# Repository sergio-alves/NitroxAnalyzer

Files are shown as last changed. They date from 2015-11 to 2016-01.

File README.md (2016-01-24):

# NitroxAnalyzer
This repository contains everything needed to build a nitrox analyzer that uses a compatible R17 O2 cell and that connects to a mobile phone running on Android.

The finished product:

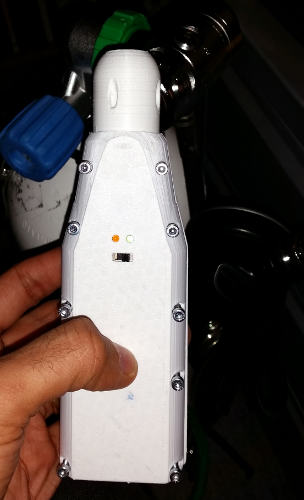
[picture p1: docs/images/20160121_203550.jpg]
The nitrox analyser V2


Read [the wiki page](https://github.com/sergio-alves/NitroxAnalyzer/wiki) to get more information about the project.

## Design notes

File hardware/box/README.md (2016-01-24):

## 3D printed box proprosition

To enclose the electronic circuitry, battery and o2 cell I propose the following box design.

* box-bottom.stl
* box-top.stl
* o2-cell-support.stl

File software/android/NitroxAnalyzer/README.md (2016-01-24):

# Nitrox Analyzer for Android

Because i'm a scubadiver, I decided to create a simple
device to read the O2 concentration of gas blends that I
breath.

I created a first version of the device using a screen
and two buttons. It worked, but someone suggested me another idea :

Why not replace the screen and buttons by an Android
application?

Benefits : Better and easy UI, less electronics, and allows me
to show that I can create an Android application that gets
data from an electronic device through a bluetooth connection.

And.... tada!!!

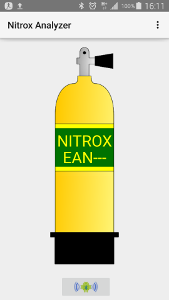
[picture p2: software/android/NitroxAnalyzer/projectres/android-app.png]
The application interface


## How it works

If automatic mode (see Settings), at startup a connection is
setup between application and the device. You can select the
interface to use in the Settings interface. If not in automatic
mode just push the radio-android :) button to start connection.

If you receive a message to ask you to activate the bluetooth
interface, just accept and click again on the connection button.
If connection succeed the animation stops.

After successful connection, comes the calibration phase.
The application will get the data coming from the device and
will average it. Calibration stops when the delta between
current value and measured average till now reaches < 1% O2.

After calibration you can start measuring all the gas blends
you want. If the interface is in continuous o2 reading (see
settings) then you just need to approach the device to the
fittings of your tank slowly open it and see the value. You
can stop when the value remains constant. If not in automatic
do the same but don't forget to click on ReadO2 button. The
analyse will finish when delta reaches < 1% O2 .

## License
GPL License

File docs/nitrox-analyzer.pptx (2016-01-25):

## DIY Nitrox Analyzer

By Sergio Alves

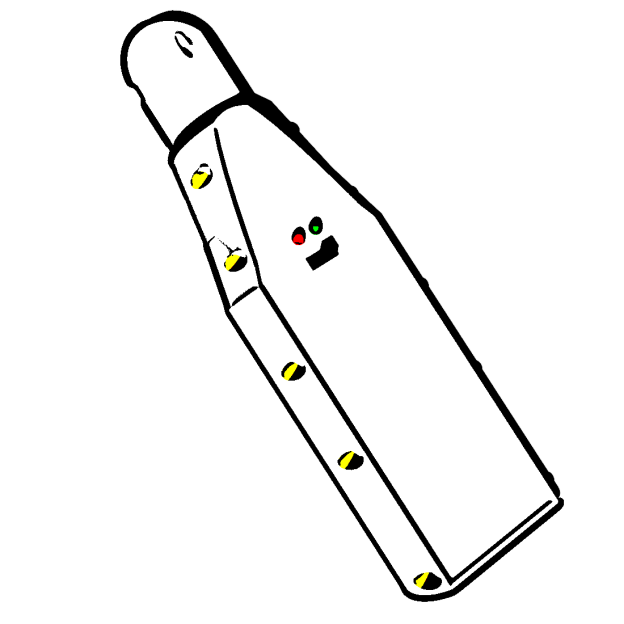
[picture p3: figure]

## Inception

- As a TEC scuba diver I often breath hyperoxic gases while decompressing (it accelerates decompression).
- To avoid entering into convulsions… and die… because of a too high ppO2, it’s important to know the precise O2 % of the gas mix and then calc the MOD (maximum operating depth) => never breath it below MOD
- Commercial analyzers are simple boxes with an O2 cell and a kind of Multimeter (really simple devices) but very expensive > 200$

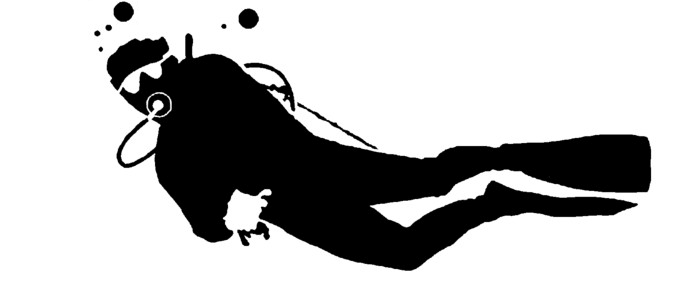
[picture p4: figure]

## Project Goals

- Build a reliable DIY device
  - Precision per bit ~300 nV
  - Price < 100 CHF
  - Open source
- Demonstrate the capacity to
  - lead a project from an idea to a finite product
  - develop C++ firmware
  - develop UI for android
  - use a Bluetooth connection
  - model/design and print a complex container (box)

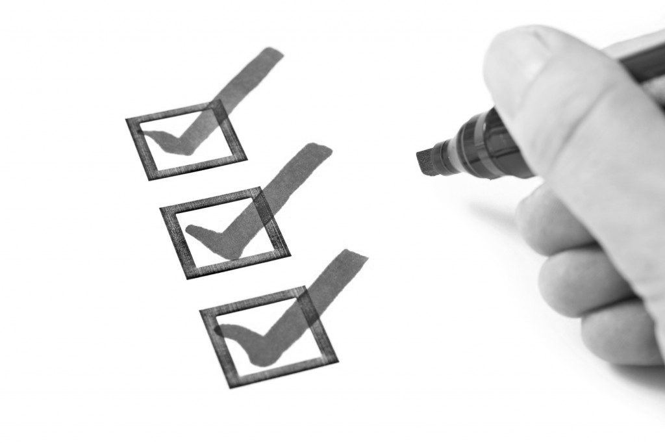
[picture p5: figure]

## How should it work ?

- Switch Analyzer on
- Launch Android application
  - If not in auto connect mode click the connection button
- After successful connection the device will enter in auto calibration mode (to get the O2 cell value for the current gaz (air ~ 20.9 % O2)
- After calibration the controller will read continuously the sensor at a rate of 1S/s (sample/second) and the application will display the O2 value

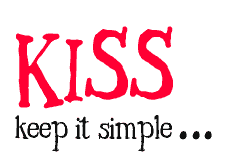
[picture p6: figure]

## How to integrate?

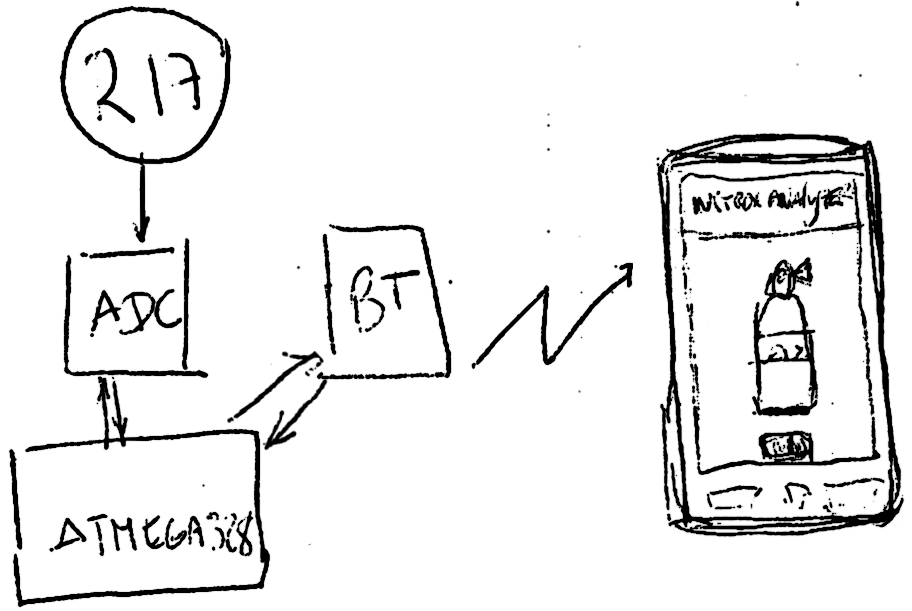
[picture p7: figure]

## Components

- Hardware
  - A 3D printed box
  - An Arduino Nano for device control
  - A Bluetooth serial module
  - A 24 bits ADC for a high signal measurement accuracy
  - R17 Medical O2 Oxygen cell sensor
- Software
  - C++ Firmware embedded in Atmega328
    - 16MHz controller with 2 Kb Ram, 32 Kb Rom (limited resources)
  - Java mobile application running on Android OS

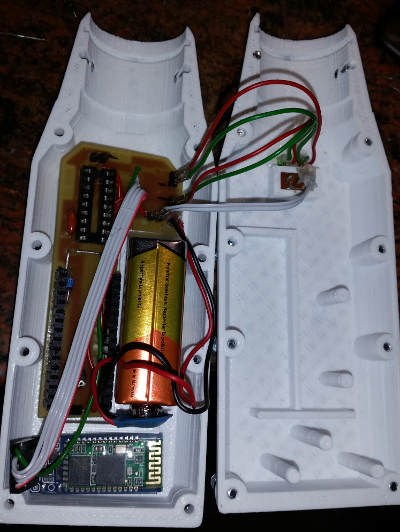
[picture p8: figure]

## Challenges

- Software
  - Create an easily upgradable protocol handler in both firmware and mobile application and make them communicate
  - Create a driver to “drive” the ADS1210 chip
- Hardware
  - Develop the smallest box able to hold a R17 cell, a Nano board, a 9V battery and a Bluetooth module
- Create something precise enough to be confident using it and that runs straight forward
- Develop a device without any kind of physical user interaction (buttons, screen, audio)

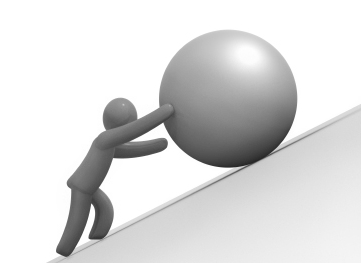
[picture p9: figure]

## How to improve?

- Features
  - connection to a Bluetooth analyzer
  - auto calibration
  - continuous o2 measurement
  - displaying o2 cell dates (install, validity)

- Wanted features
  - update install validity dates
  - display progress bar to help to know when a measure is valid
  - keep a track of read values
  - creates a more TEC view with higher precision
  - allow to have 2 O2 cells to have a duplicate measure. This will render the device very safe and avoid wrong measures

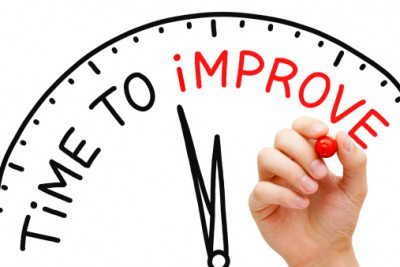
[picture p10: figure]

## Some time later…

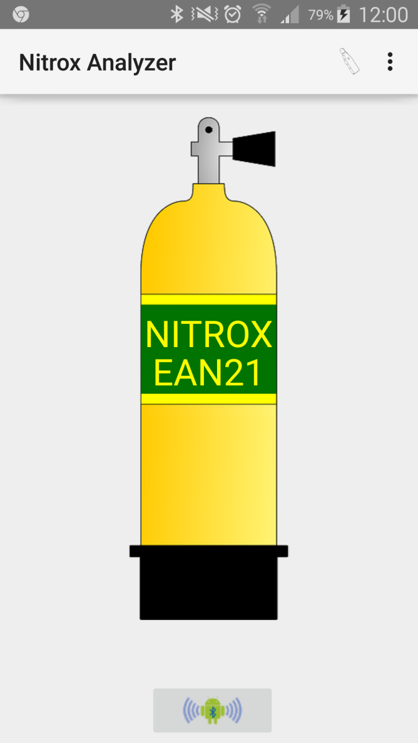
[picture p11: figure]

## Because I belive in pen Source

- All files, schemas, images, source codes are available and licensed under GNU GPL3 on
https://github.com/sergio-alves/NitroxAnalyzer

## Live demo

- Lets see how KISS is it !!!

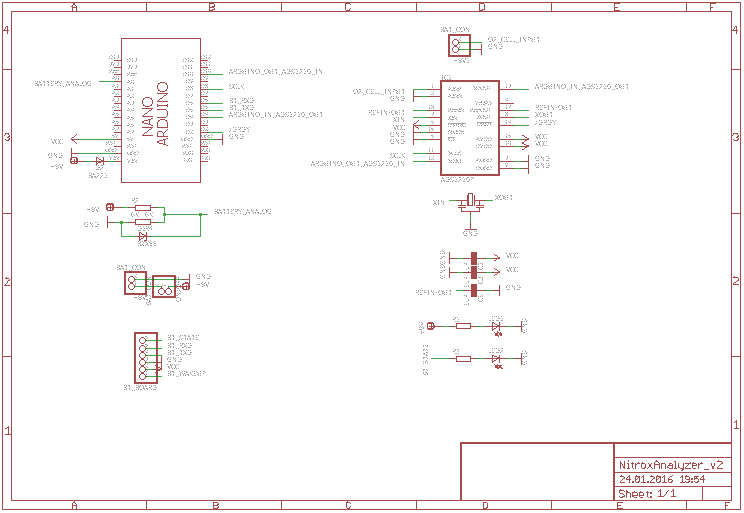
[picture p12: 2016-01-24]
docs/images/schematic.png

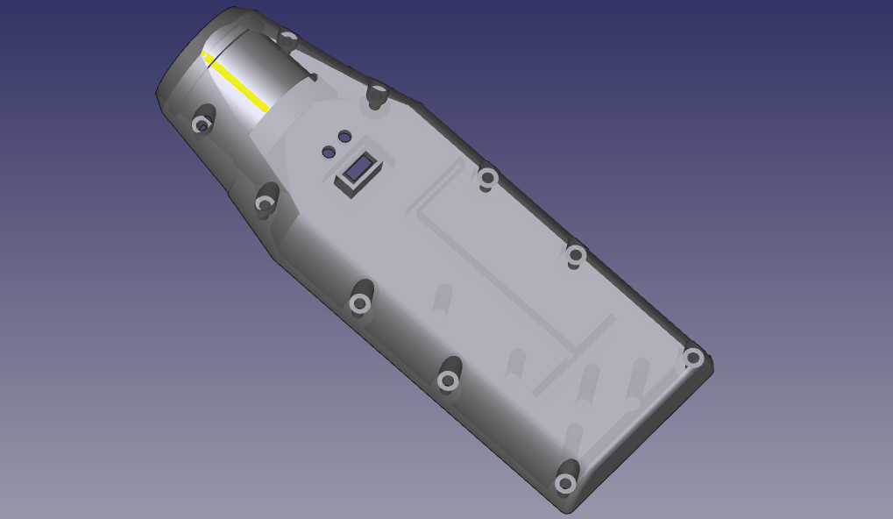
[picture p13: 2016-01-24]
docs/images/box-top.png

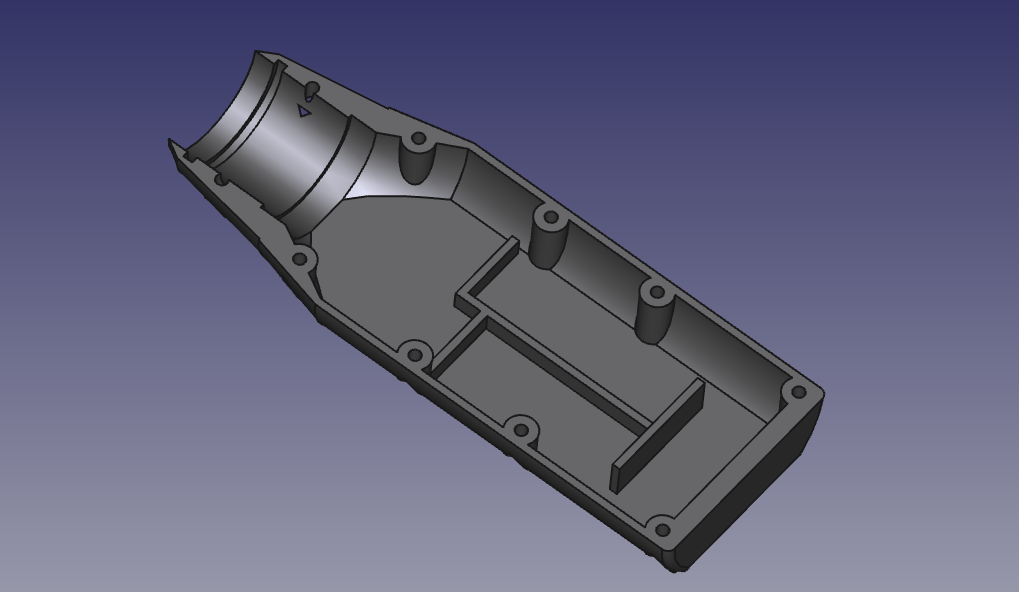
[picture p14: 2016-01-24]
docs/images/box-bottom.png

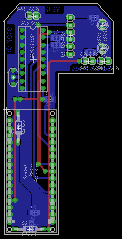
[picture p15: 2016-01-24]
docs/images/board.png

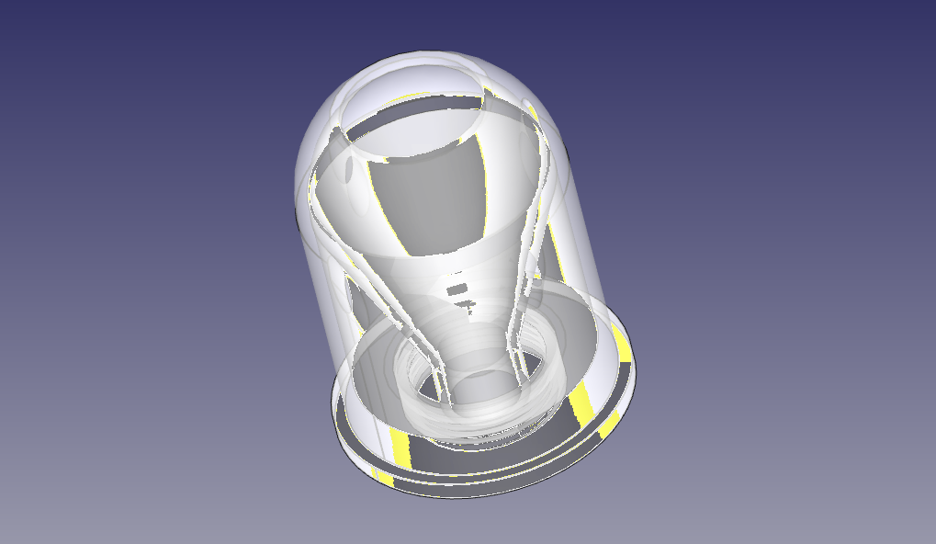
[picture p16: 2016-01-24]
docs/images/o2-cell-support.png

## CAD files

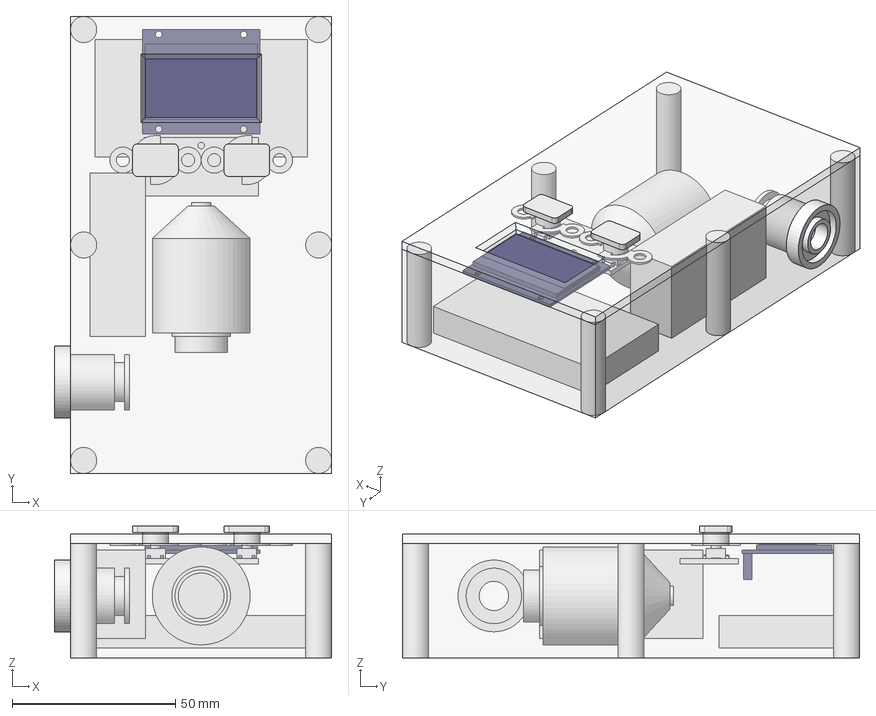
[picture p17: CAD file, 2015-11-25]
box/freecad files/NitroxAnalyzer.FCStd
85.0 x 140.0 x 40.4 mm
battery
board_nano
oled-screen
case-top
start-button
buttons-pcb
calibrate-button
o2_cell
propeller
fittings-connector
flow-pipe
bottom-box

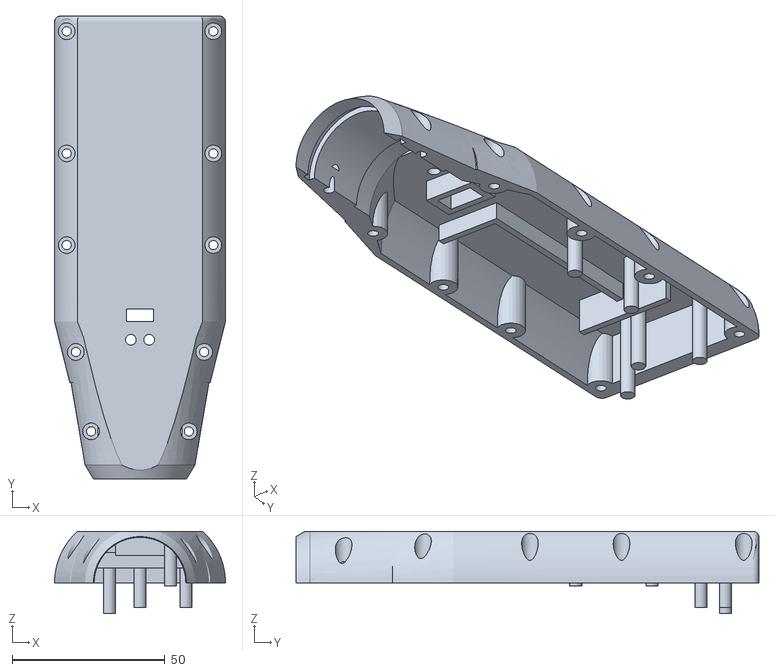
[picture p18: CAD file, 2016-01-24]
hardware/box/box-top.stl
56.0 x 151.6 x 27.0

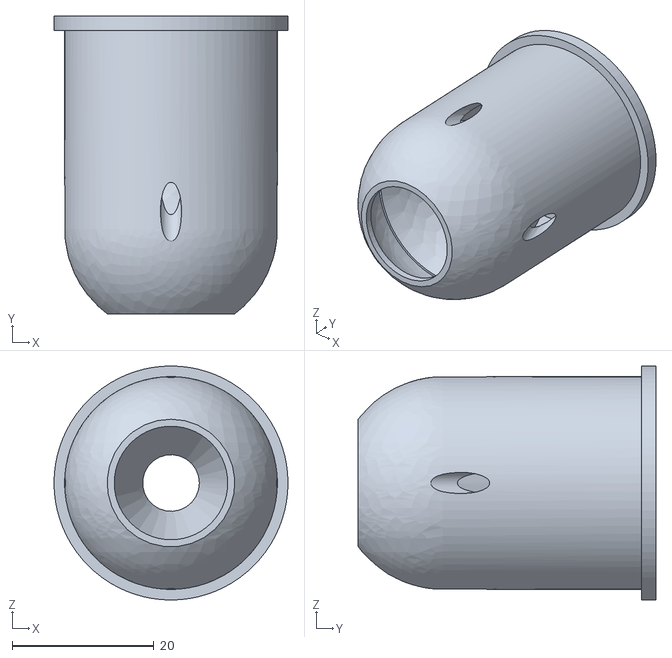
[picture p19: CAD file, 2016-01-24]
hardware/box/o2-cell-support.stl
33.0 x 42.0 x 33.0

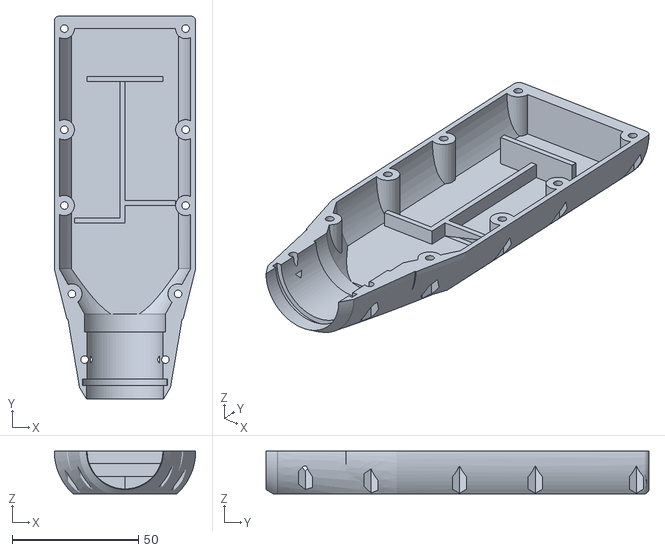
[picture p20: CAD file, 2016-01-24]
hardware/box/box-bottom.stl
56.0 x 151.6 x 17.0

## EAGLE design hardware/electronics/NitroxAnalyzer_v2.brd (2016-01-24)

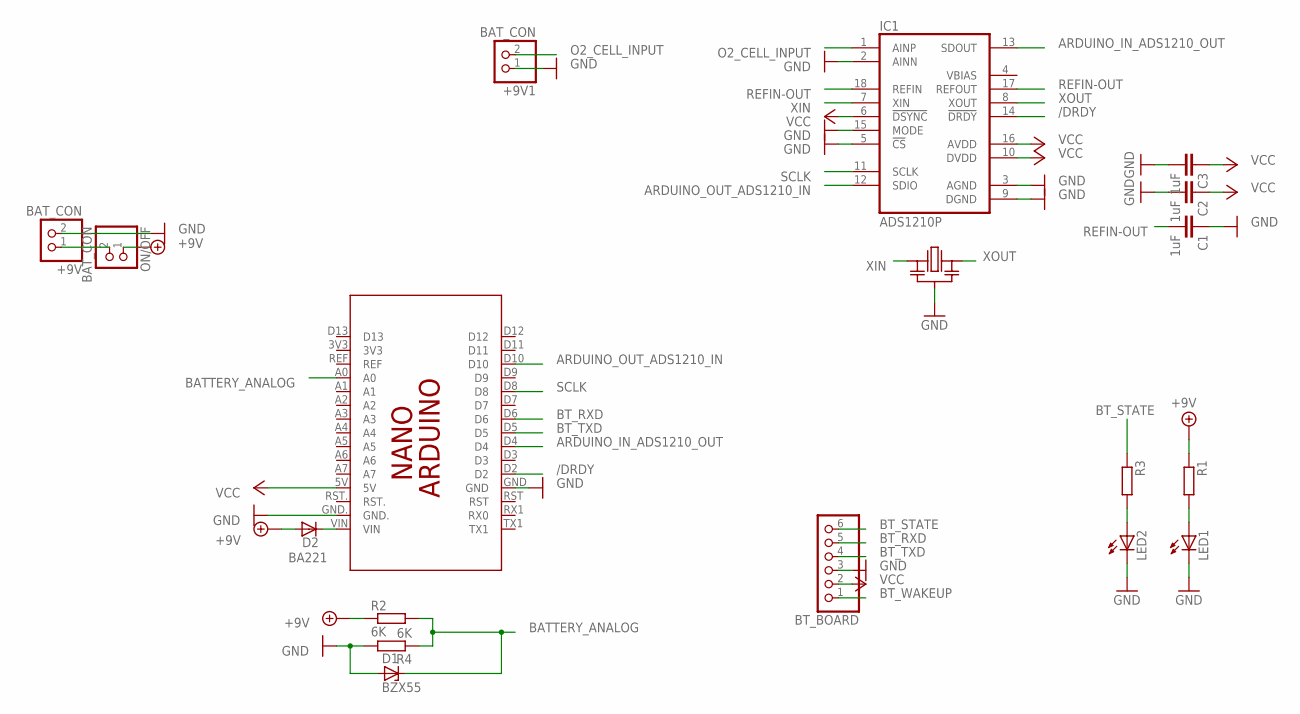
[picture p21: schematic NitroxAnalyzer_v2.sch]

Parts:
+9V, +9V1: BAT_CON; 1X02
BT_BOARD: PINHD-1X6; 1X06
C1, C2, C3: 1uF; C1206
D1: BZX55; DO35Z10
D2: BA221; DO35-10
IC1: ADS1210P; DIL18
LED1, LED2: LED3MM
ON/OFF: BAT_CON; 1X02
PCB1: ARDUINO_NANO_SOCKET
R1, R3: R-EU_R1206; R1206
R2, R4: 6K; R1206
U$2: RESONATOR

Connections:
+9V: D2.A, ON/OFF.1, R1.1, R2.1
/DRDY: IC1.14 (!DRDY), PCB1.D2
ARDUINO_IN_ADS1210_OUT: IC1.13 (SDOUT), PCB1.D4
ARDUINO_OUT_ADS1210_IN: IC1.12 (SDIO), PCB1.D10
BATTERY_ANALOG: D1.C, PCB1.A0, R2.2, R4.1
BT_RXD: BT_BOARD.5, PCB1.D6
BT_STATE: BT_BOARD.6, R3.1
BT_TXD: BT_BOARD.4, PCB1.D5
BT_WAKEUP: BT_BOARD.1
GND: +9V.2, +9V1.1, BT_BOARD.3, C1.1, C2.2, C3.2, D1.A, IC1.2 (AINN), IC1.3 (AGND), IC1.5 (!CS), IC1.9 (DGND), IC1.15 (MODE), LED1.K (C), LED2.K (C), PCB1.GND, PCB1.GND., R4.2, U$2.P$2 (GND)
unnamed: D2.C, PCB1.VIN
unnamed: LED1.A, R1.2
unnamed: LED2.A, R3.2
unnamed: +9V.1, ON/OFF.2
O2_CELL_INPUT: +9V1.2, IC1.1 (AINP)
REFIN-OUT: C1.2, IC1.17 (REFOUT), IC1.18 (REFIN)
SCLK: IC1.11 (SCLK), PCB1.D8
VCC: BT_BOARD.2, C2.1, C3.1, IC1.6 (!DSYNC), IC1.10 (DVDD), IC1.16 (AVDD), PCB1.5V
XIN: IC1.7 (XIN), U$2.P$1 (IN)
XOUT: IC1.8 (XOUT), U$2.P$3 (OUT)

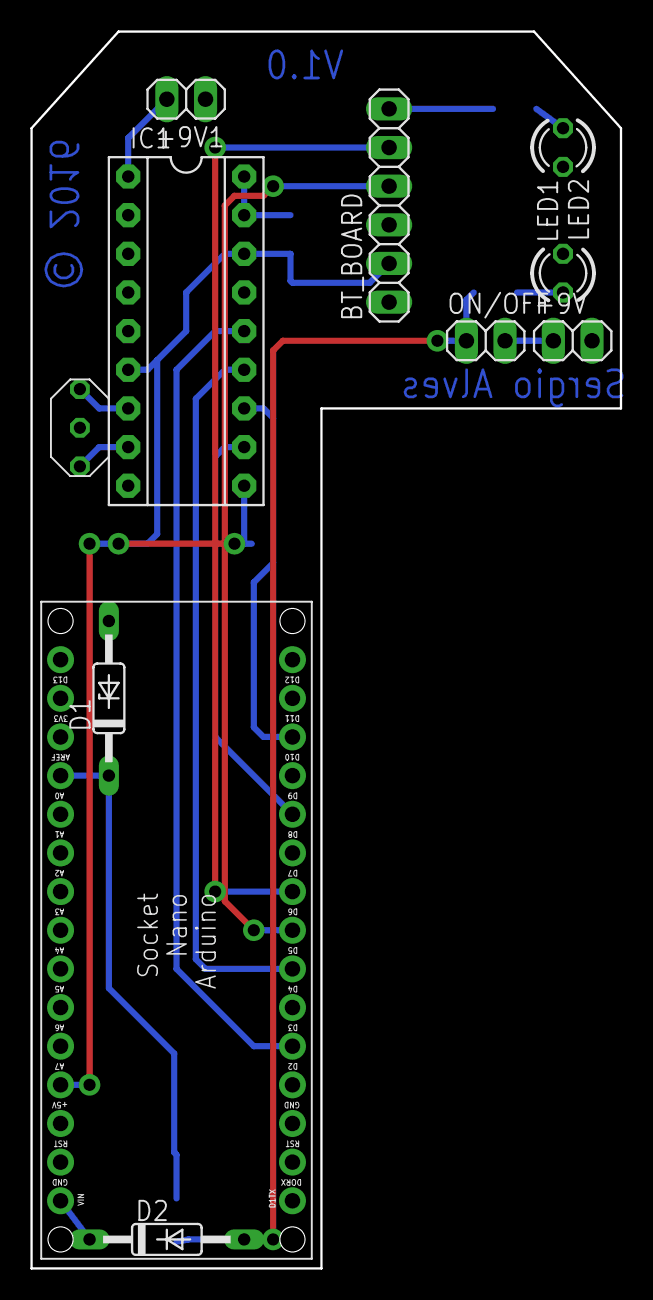
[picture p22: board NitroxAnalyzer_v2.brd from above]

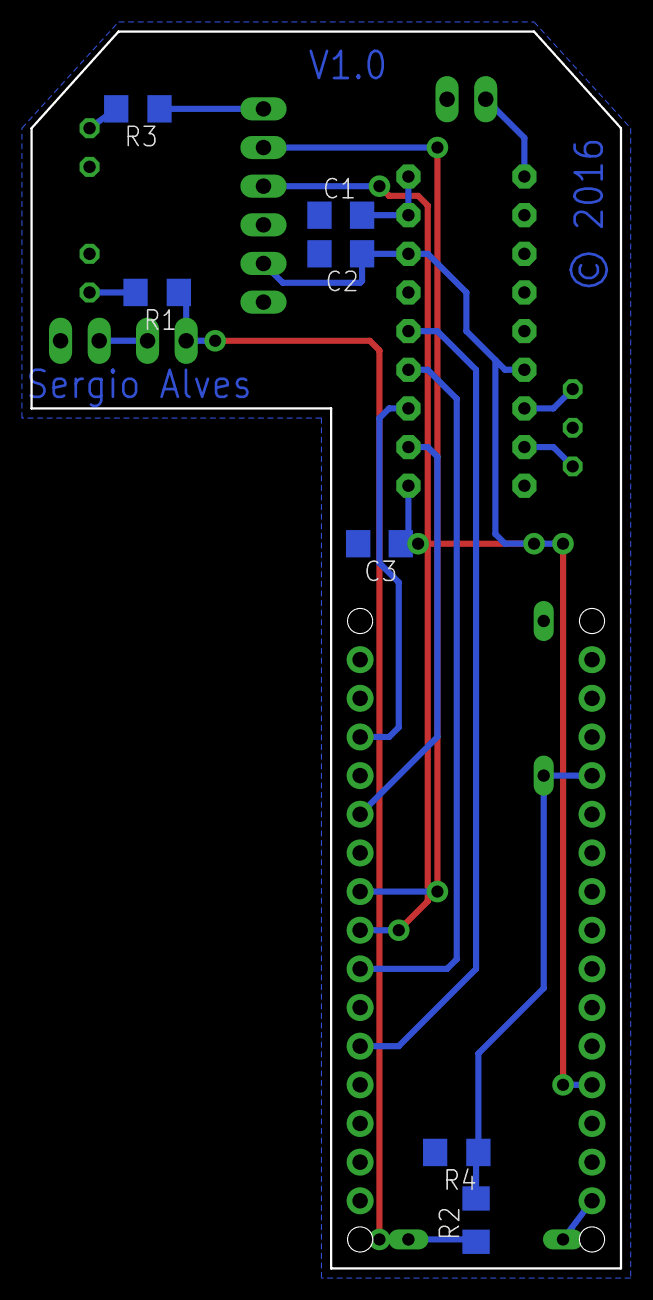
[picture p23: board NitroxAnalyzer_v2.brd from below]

Board: 2 copper layers, 38.7 x 81.3 mm, 18 parts (7 on the bottom side), 19 nets.

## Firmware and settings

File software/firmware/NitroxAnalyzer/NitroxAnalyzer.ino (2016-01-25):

#include <SoftwareSerial.h>
#include <SPI.h>
#include <stdio.h>
#include <EEPROM\EEPROM.h>
#include "ADS1210Driver.h"
#include "SerialProtocolHandler.h"

#define SOFTWARE_RX_PIN					5
#define SOFTWARE_TX_PIN					6

#define ADS1210_CLK						8
#define ARDUINO_OUT_ADS1210_IN			10
#define ARDUINO_IN_ADS1210_OUT			4

#define BATTERY_AD_INPUT				A0

#define EEPROM_STORED_DATA_SIZE			12
#define EEPROM_CONFIG_START_ADDRESS		0

typedef struct {
	int day;
	int month;
	int year;
} date;

typedef union {
	byte data[EEPROM_STORED_DATA_SIZE];
	struct {
		long clean;
		struct {
			date install_date; //6 bytes
			date change_date;  //6 bytes
		} O2Cell; // 12 bytes
	};
} EEPROMContent;

typedef union {
	struct {
		unsigned crap : 1;
		unsigned value : 12;
		unsigned padding : 3;
	} bitfield;
	struct {
		byte low;
		byte high;
	}bytes;
	unsigned int raw;
} DWORD_MAX_187_DATA_FORMAT; //2 bytes

typedef union {
	char bytes[6];
	struct {
		unsigned int start;
		unsigned int current;
		unsigned int end;
	}structuredData;
} SendingBuffer;

enum States {
	STATE_IDLE,
	STATE_EXECUTE_GET_AVERAGE_INIT,
	STATE_EXECUTE_GET_AVERAGE_READ_VALUES,
	STATE_EXECUTE_GET_AVERAGE_RETURN_RESPONSE,
	STATE_EXECUTE_GET_BATTERY_LOAD,
	STATE_EXECUTE_GET_O2_CELL_INSTALL_DATE,
	STATE_EXECUTE_SET_O2_CELL_INSTALL_DATE,
};

SoftwareSerial BTSerial = SoftwareSerial(SOFTWARE_RX_PIN, SOFTWARE_TX_PIN);
SerialProtocolHandler protocolHandler = SerialProtocolHandler(BTSerial);
EEPROMContent eeprom;

#define isEEPROMClean() eeprom.clean==0xCAFEBABE

SendingBuffer sb;
DWORD_MAX_187_DATA_FORMAT current;
char buffer[128];
char c;
SerialCommand * command;
States state = STATE_IDLE;
bool readMeasure = false;
unsigned long average;
int counter = 0;
int maxIterations = 10;
long min = 0x7FFFFFFF;
long max = 0x80000000;


/* This app setup*/
void setup()
{
	Serial.begin(115200);
	BTSerial.begin(9600);

	attachInterrupt(digitalPinToInterrupt(2), newMeasure, FALLING);

	ads1210.begin(ADS1210_CLK, ARDUINO_OUT_ADS1210_IN, ARDUINO_IN_ADS1210_OUT);

	pinMode(BATTERY_AD_INPUT, INPUT);

	//Load eeprom
	for (int i = 0; i < EEPROM_STORED_DATA_SIZE; i++) {
		eeprom.data[i] = EEPROM.read(EEPROM_CONFIG_START_ADDRESS + i);
	}
}

void newMeasure() {
	readMeasure = true;
}

void readAndIncrement() {
	long l;

	if (readMeasure) {
		l = ads1210.readDataOutputRegister();

		if (l < min)
			min = l;
		if (l > max)
			max = l;

		average += l;
		counter++;
	}
}

void loop() {
	unsigned int mappedVal = 0, val = 0;

	//Handle protocol
	switch (state) {
	case STATE_EXECUTE_GET_AVERAGE_INIT:
		maxIterations = ((GetAverageCommand *)command)->getIterations();
		state = STATE_EXECUTE_GET_AVERAGE_READ_VALUES;
		break;
	case STATE_EXECUTE_GET_AVERAGE_READ_VALUES:
		if (counter == maxIterations) { state = STATE_EXECUTE_GET_AVERAGE_RETURN_RESPONSE; }
		else { readAndIncrement(); }
		break;
	case STATE_EXECUTE_GET_AVERAGE_RETURN_RESPONSE:
		average = (long)(average / (float)maxIterations);
		((GetAverageCommand *)command)->setAverage(average);

		protocolHandler.sendResponse(command);

		sprintf(buffer, "Average ater %i iterations : (min, max, max-min, average)=>(%li, %li, %li, %li)\0", maxIterations, min, max, max - min, average);
		Serial.println(buffer);

		counter = 0;
		average = 0;
		min = 0x7FFFFFFF;
		max = 0x80000000;
		state = STATE_IDLE;
		break;
	case STATE_EXECUTE_GET_BATTERY_LOAD:
		//long v = analogRead(BATTERY_AD_INPUT);
		//When battery is full  A0 reads value 4.4 Volts => 0.55 * 8V
		//		int value = map(analogRead(BATTERY_AD_INPUT), 0, 1023, 0, 5);
		//9 = 4.5 = batter full
		//6 = 3 = battery quite empty

		// ==> 950 max  600 min
		val = analogRead(BATTERY_AD_INPUT);
		delayMicroseconds(100);
		val = analogRead(BATTERY_AD_INPUT);
		Serial.print("Analog read A0 = ");
		Serial.println(val);

		if (val < 650)
			mappedVal = 0;
		if (val > 850)
			mappedVal = 100;
		if (val >= 650 && val <= 850)
			mappedVal = (int)((val - 650) / 2.0);

		Serial.print("Mapped read A0 = ");
		Serial.println(mappedVal);
		((GetBatteryLoadCommand *)command)->setLoad(mappedVal);
		protocolHandler.sendResponse(command);
		state = STATE_IDLE;
		break;
	case STATE_EXECUTE_GET_O2_CELL_INSTALL_DATE:
		if (isEEPROMClean()) {
			((GetO2CellInstallDateCommand *)command)->setDate(eeprom.O2Cell.install_date.day, eeprom.O2Cell.install_date.month, eeprom.O2Cell.install_date.year);
			protocolHandler.sendResponse(command);
		}
		else{
			
			protocolHandler.sendErrorResponse(1, "No valid clean install date found");
		}
		state = STATE_IDLE;
		break;
	case STATE_EXECUTE_SET_O2_CELL_INSTALL_DATE:
		eeprom.O2Cell.install_date.day = ((SetO2CellInstallDateCommand *)command)->getDay();
		eeprom.O2Cell.install_date.month = ((SetO2CellInstallDateCommand *)command)->getMonth();
		eeprom.O2Cell.install_date.year = ((SetO2CellInstallDateCommand *)command)->getYear();

		if (eeprom.clean != 0xCAFEBABE) {
			eeprom.clean = 0xCAFEBABE;
			eeprom.O2Cell.change_date.day = eeprom.O2Cell.install_date.day;
			eeprom.O2Cell.change_date.month = eeprom.O2Cell.install_date.month;
			eeprom.O2Cell.change_date.year = eeprom.O2Cell.install_date.year + 3;
		}

		//Load eeprom
		for (int i = 0; i < EEPROM_STORED_DATA_SIZE; i++) {
			EEPROM.write(EEPROM_CONFIG_START_ADDRESS + i, eeprom.data[i]);
		}

		protocolHandler.sendResponse(command);
		state = STATE_IDLE;
		break;
	case STATE_IDLE:
	default:
		command = protocolHandler.getNextCommand();

		if (command != NULL) {
			switch ((int)command->getCommandID()) {
			case GET_AVERAGE:
				state = STATE_EXECUTE_GET_AVERAGE_INIT;
				break;
			case GET_BATTERY_LOAD:
				state = STATE_EXECUTE_GET_BATTERY_LOAD;
				break;
			case GET_O2_CELL_INSTALL_DATE:
				state = STATE_EXECUTE_GET_O2_CELL_INSTALL_DATE;
				break;

			case SET_O2_CELL_INSTALL_DATE:
				state = STATE_EXECUTE_SET_O2_CELL_INSTALL_DATE;
				break;
			default:
				state = STATE_IDLE;
				break;
			}
		}
	}

	//readMeasure is updated by interrupt each type a new value from ads1210 is available
	readMeasure = false;
}

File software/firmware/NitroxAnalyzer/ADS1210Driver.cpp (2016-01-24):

#include "ADS1210Driver.h"


ADS1210Driver::ADS1210Driver(unsigned long freqIn)
{
	ADS1210Driver::frequencyIn = freqIn;
}

void ADS1210Driver::begin(byte clk, byte arduinoOutADS1210In, byte arduionInADS1210Out) {
	din_pin = arduionInADS1210Out;
	dout_pin = arduinoOutADS1210In;
	clk_pin = clk;

	pinMode(din_pin, INPUT_PULLUP);
	pinMode(dout_pin, OUTPUT);
	pinMode(clk_pin, OUTPUT);

	digitalWrite(clk_pin, LOW);
	digitalWrite(dout_pin, LOW);

	//setup chip configuration 
	insreg.bits.rw = WRITE;
	insreg.bits.mb = _4BYTES;
	insreg.bits.address = COMMAND_REGISTER_BYTE_3_MSB;
	
	/*
	Serial.print(F("INSREG = "));
	Serial.println(insreg.insr);
	*/

	//defaults
	creg.bias = Off;
	creg.referenceOutput = On;
	creg.dataFormat = TwosComplement;
	creg.unipolar = Bipolar;
	creg.byteOrder = MostSignificantByteFirst;
	creg.bitOrder = MostSignificantBitFirst;
	creg.serialDataLine = SDOUT;
	creg.operationMode = BackgroundCalibration;
	creg.pgaMode = GAIN_2;
	creg.channel = Channel1;
	creg.turboMode = TurboModeRate16;

	/* Works as expected 
	==============================================
	Serial.print(F("CREG[3] = "));
	Serial.println(creg.cmr[3]);
	Serial.print(F("CREG[2] = "));
	Serial.println(creg.cmr[2]);
	Serial.print(F("CREG[1] = "));
	Serial.println(creg.cmr[1]);
	Serial.print(F("CREG[0] = "));
	Serial.println(creg.cmr[0]);
	*/
	//calculate decimation rate 5 times per second
	calculateAndSetDecimationRate(50);

	//Write command
	//should set dio_pin as output
	//pinMode(dio_pin, OUTPUT);

	//transmit instruction byte
	transmitByte(insreg.insr);

	//transmitting command byte
	for (int i = 3; i >= 0; i--) {
		transmitByte(creg.cmr[i]);
	}

	Serial.print(F("Sent configuration to ads1210 : ("));
	for (int i = 3; i >= 0; i--) {
		Serial.print(creg.cmr[i]);
		if (i>0)
			Serial.print(F(")-("));
		else 
			Serial.print(F(")"));
	}

	Serial.println();


	//Now Read the configuration
	
	CommandRegister cr;

	//Readcommand
	insreg.bits.rw = READ;
	insreg.bits.mb = _4BYTES;
	insreg.bits.address = COMMAND_REGISTER_BYTE_3_MSB;

	transmitByte(insreg.insr);

	if (DEBUG)
		Serial.print("Receiving Data : ");

	for (int i = 3; i >= 0; i--) {
		cr.cmr[i] = receiveByte();
	}

	if (DEBUG)
		Serial.println();

	if ((cr.cmr[3] & 0xFE) != (creg.cmr[3]&0xFE)) {
		Serial.println(F("We have a very big problem :::::: cannot get or write right creg values from ads1210."));
	}
}

ADS1210Driver::~ADS1210Driver()
{

}

void ADS1210Driver::calculateAndSetDecimationRate(int fData) {
	double tmr;

	//Cannot be faster
	if (fData > 1000)
		fData = 1000;

	if (DEBUG) {
		char buffer[64];
		if (DEBUG)
			sprintf(buffer, "frequencyIn, turboMode,fdata -> %lu, %i, %i\\0", frequencyIn, creg.turboMode, fData) ;
		Serial.println(buffer);
	}

	double decimationRatio = (((double)frequencyIn * pow(2,(double)creg.turboMode)) / ((double)fData*512.0)) - 1.0;

	if (DEBUG) {
		Serial.print(F("Calculated DecimationRation for data frequency "));
		Serial.print(fData);
		Serial.print(F(" = "));
		Serial.println(decimationRatio);
	}

	//cannot be greater
	if (decimationRatio >= 8000)
		decimationRatio = 7999;

	//cannot be smaller
	if (decimationRatio < 19)
		decimationRatio = 19;

	creg.decimationRatio = (int)decimationRatio;
}

boolean ADS1210Driver::isPGAControlCorrectBasedOnTurboModeRate() {
	return pga2trm(creg.pgaMode, creg.turboMode);
}

boolean ADS1210Driver::pga2trm(int a, int b) {
	switch (a) {
	case 0:
		return true;
	case 1:
		if (b <= 8)
			return true;
		break;
	case 2:
		if (b <= 4)
			return true;
		break;
	case 3:
		if (b <= 2)
			return true;
		break;
	case 4:
		if (b == 1)
			return true;
		break;
	}

	return false;
}

boolean ADS1210Driver::isTurboModeRateCorrectBasedOnPGAControl(){
	return pga2trm(creg.turboMode, creg.pgaMode);
}

boolean ADS1210Driver::setTurboMode(ComReg_TurboModeRate tmr){
	if (isTurboModeRateCorrectBasedOnPGAControl()) {
		creg.turboMode = tmr;
	}
}

boolean ADS1210Driver::setGain(ComReg_GainSetting gain){
	if (isPGAControlCorrectBasedOnTurboModeRate()) {
		creg.pgaMode = gain;
	}
}

/*
Reads the content of the Data Output Register. creg Bit and Byte order are supported.
*/
long ADS1210Driver::readDataOutputRegister() {
	long data = 0;
	unsigned long l;
	boolean msb = creg.byteOrder == MostSignificantByteFirst;

	//set isnreg stuff and sendit
	insreg.bits.rw = READ;
	insreg.bits.mb = _3BYTES;
	insreg.bits.address = DATA_OUTPUT_REG_BYTE_2_MSB;

	//Normally called just after a DRDY low detection
	delayMicroseconds(1); // min 5.5 * 100 nS => 550 ns  then 1 Us should be enough

	//write insr 
	transmitByte(insreg.insr);
	delayMicroseconds(10);

	for (int i = (msb ? insreg.bits.mb : 0); (msb ? i >= 0 : i <= insreg.bits.mb); (msb? i--: i++)) {
		//get byte
		l = receiveByte();
		data += (l << (8 * i));
		
		//set data sign if twos complement
		if (creg.dataFormat == TwosComplement ) {
			if (msb) {
				if (insreg.bits.mb == i && insreg.bits.mb<3)
					data += ((l & 0x80) << 24);
			}
			else{

			}
		}

		if (DEBUG) {
			Serial.print("{");
			Serial.print(l);
			Serial.print(", ");
			Serial.print(data);
			Serial.println("}");
		}
	}
	
	return data;
}

/*
Send a bit to the ADS1210 IC
*/
void ADS1210Driver::transmitBit(byte bit) {
	digitalWrite(clk_pin, HIGH);
	digitalWrite(dout_pin, bit);
	delayMicroseconds(1);
	digitalWrite(clk_pin, LOW);
	delayMicroseconds(1);
}

/*
Sends a byte to the ADS1210 IC
*/
void ADS1210Driver::transmitByte(byte value) {
	byte bit;

	//set clock to low
	digitalWrite(clk_pin, LOW);

	for (int i = 7; i >= 0; i--) {
		bit = value;
		bit &= (1 << i);
		bit >>= i;
		transmitBit(bit);
	}
}

/*
Receives a bit from the ADS1210 IC
*/
byte ADS1210Driver::receiveBit() {
	byte b;
	digitalWrite(clk_pin, HIGH);
	delayMicroseconds(1);
	digitalWrite(clk_pin, LOW);
	b = digitalRead(din_pin);
	delayMicroseconds(1);

	if (DEBUG)
		Serial.print(b);

	return b;
}

/*
Receives one byte from the ADS1210 IC
*/
byte ADS1210Driver::receiveByte() {
	byte b = 0;
	byte received = 0;
	boolean msb = creg.bitOrder == MostSignificantBitFirst;

	//set clock to low
	digitalWrite(clk_pin, LOW);

	if (DEBUG)
		Serial.print(" {");

	for (int i = (msb ? 7 : 0); (msb ? i >= 0 : i<=0); (msb? i--: i++)) {
		received = receiveBit();
		//Serial.print(received);
		b += (received << i);
	}

	if (DEBUG) {
		Serial.print(" = ");
		Serial.print(b);
		Serial.print("}");
	}

	return b;
}

//10MHz = the resonator frequency
ADS1210Driver ads1210 = ADS1210Driver(10000000);

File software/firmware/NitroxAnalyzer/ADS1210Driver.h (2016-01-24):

#pragma once

#include <Arduino.h>

#define DEBUG true

typedef enum ReadWrite{
	WRITE = 0,
	READ
} InstructionReg_RW;

typedef enum  MultiByte{
	_1BYTE = 0,
	_2BYTES,
	_3BYTES,
	_4BYTES
} InstructionReg_MB;

typedef enum CommandAddress{
	DATA_OUTPUT_REG_BYTE_2_MSB = 0,
	DATA_OUTPUT_REG_BYTE_1,
	DATA_OUTPUT_REG_BYTE_0_LSB,

	COMMAND_REGISTER_BYTE_3_MSB = 4,
	COMMAND_REGISTER_BYTE_2,
	COMMAND_REGISTER_BYTE_1,
	COMMAND_REGISTER_BYTE_0_LSB,

	OFFSET_CAL_REGISTER_BYTE_2_MSB = 8,
	OFFSET_CAL_REGISTER_BYTE_1,
	OFFSET_CAL_REGISTER_BYTE_0_LSB,

	FULL_SCALE_CAL_REG_BYTE_2_MSB = 12,
	FULL_SCALE_CAL_REG_BYTE_1,
	FULL_SCALE_CAL_REG_BYTE_0_LSB,
} InstructionReg_CommandAddress;

typedef union InstructionRegister{
	byte insr;
	struct {
		unsigned address : 4; //LSBit
		unsigned : 1;
		unsigned mb : 2;
		unsigned rw : 1; //MSBit
	} bits;
} InstructionReg;


typedef enum OnOff{
	Off = 0,
	On
} ComReg_Bias, ComReg_ReferenceOutput;

typedef enum DataFormat{
	TwosComplement = 0,
	OffsetBinary
} ComReg_DataFormat;

typedef enum Polarity{
	Bipolar = 0,
	Unipolar
} ComReg_Unipolar;

typedef enum  BytOrder{
	MostSignificantByteFirst = 0,
	LeastSignificantByteFirst
} ComReg_ByteOrder;

typedef enum BitOrder{
	MostSignificantBitFirst = 0,
	LeastSignificantBitFirst
} ComReg_BitOrder;

typedef enum SerialDataOutputPin{
	SDIO = 0, 
	SDOUT
} ComReg_SerialDataOutputPin;

typedef enum DataReady{
	DataReady = 0,
	DataNotReady
} ComReg_DataReady;

typedef enum OperatingMode{
	NormalMode = 0,
	SelfCalibration,
	SystemOffsetCalibration,
	SystemFullScaleCalibration,
	PseudoSystemCalibration,
	BackgroundCalibration,
	Sleep,
	Reserved
} ComReg_OperatingMode;

typedef enum GainSetting{
	GAIN_1 = 0,
	GAIN_2,
	GAIN_4,
	GAIN_8,
	GAIN_16
} ComReg_GainSetting;

typedef enum  Channels{
	Channel1 = 0,
	Channel2,
	Channel3,
	Channel4
} ComReg_Channels;

typedef enum TurboModeRate{
	TurboModeRate1 = 0,
	TurboModeRate2,
	TurboModeRate4,
	TurboModeRate8,
	TurboModeRate16
} ComReg_TurboModeRate;


typedef union CommandRegister{
	byte cmr[4];
	struct {
		unsigned decimationRatio : 13; // LSByte and LSBit
		unsigned turboMode : 3;	// default turbo mode rate = 1				
		unsigned channel : 2;	// default 00 Channel 1
		unsigned pgaMode : 3;	// default 000 Gain 1
		unsigned operationMode : 3;	// default 000 Normal Mode	
		unsigned dataReady : 1;	// no default
		unsigned serialDataLine : 1;	// default SDIO	
		unsigned bitOrder : 1;	// defualt MSbit first
		unsigned byteOrder : 1;	// default MSB first MostSignificantByteFirst
		unsigned unipolar : 1;	// default bipolar	
		unsigned dataFormat : 1;	// default off => Two's complement
		unsigned referenceOutput : 1;	// default on
		unsigned bias : 1;	// default off				MSBYTE and MSBit
	};
} CommandRegister;


class ADS1210Driver
{
public:
	ADS1210Driver(unsigned long ads1210Frequency);
	~ADS1210Driver();
	void begin(byte clk, byte dIn, byte dOut);
	long readDataOutputRegister();

protected:
	void calculateAndSetDecimationRate(int fData);
	boolean isPGAControlCorrectBasedOnTurboModeRate();
	boolean isTurboModeRateCorrectBasedOnPGAControl();
	void transmitByte(byte value);
	void transmitBit(byte value);
	byte receiveByte();
	byte receiveBit();

private:
	unsigned long frequencyIn;
	byte clk_pin;
	byte din_pin;
	byte dout_pin;

	void setDecimationRate();
	boolean pga2trm(int a, int b);

	boolean setTurboMode(ComReg_TurboModeRate tmr);
	boolean setGain(ComReg_GainSetting gain);

	CommandRegister creg;
	InstructionReg insreg;
};

extern ADS1210Driver ads1210;

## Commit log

2015-11-25 First iteration for the nitrox analyzer.
    There is a first version for :
    - The box (freecad file)
    - The firmware (arduino file)
    - The hardware (eagle file)
    And a helper project used to convert pbm files into a byte array convenient to api used to communicate with the ssd1306 display controller
    [NitroxAnalyzer.FCStd, NitroxAnalyzer.brd, NitroxAnalyzer.sch]
2015-11-25 added basic firmware flowchart to resources
2015-11-27 The arduino library to communicate with my OLED screen.
2015-11-27 Updated a bit the buttons hardware board to better match the 3d box
    [NitroxAnalyzer.brd, NitroxAnalyzer.sch]
2015-11-27 The fittings connector that will direct the nitrox flux from the tank to the analyzer
    [fittings-connector.stl]
2015-11-27 Updated the Code to decouple the AnalyzerApp from the screen driver
2015-11-28 Updated some 3d cad models and other stuff
    [NitroxAnalyzer.brd, NitroxAnalyzer.sch, board.stl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]
2016-01-08 last commit on this solution.
    I got some drawbacks that force to change the approach.
    1- No more screen and buttons but an Android interface
    2- Bluetooth Connection will be used
    [NitroxAnalyzer.brd, NitroxAnalyzer.sch, Propeler.FCStd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]
2016-01-24 - moved android app to the project
    - refactored android app
    - added box v2
    - added circuit v2 that fits box v2
    - added presentation of the project
    [NitroxAnalyzer_v2.brd, NitroxAnalyzer_v2.sch, box-top.stl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]
2016-01-24 moved projects
    [Propeler.FCStd, box-bottom.stl, box-top.stl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]
2016-01-24 moving files + exported 3D parts for the box
    [NitroxAnalyzer - Copie.brd, NitroxAnalyzer.brd, NitroxAnalyzer.sch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]
2016-01-24 added some new images
    [graphs.xlsx]
2016-01-24 added images of schematic and board
    [NitroxAnalyzer_v2.sch]
2016-01-24 Delete NitroxAnalyzer.sch
    doen't need it anymore
    [NitroxAnalyzer.sch]
2016-01-24 Delete NitroxAnalyzer.brd
    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
    [NitroxAnalyzer.brd]
2016-01-24 Delete NitroxAnalyzer - Copie.brd
    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
    [NitroxAnalyzer - Copie.brd]
2016-01-25 fixed small bug when app lose connection
    [NitroxAnalyzer.ino]

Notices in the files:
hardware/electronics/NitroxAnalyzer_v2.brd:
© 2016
